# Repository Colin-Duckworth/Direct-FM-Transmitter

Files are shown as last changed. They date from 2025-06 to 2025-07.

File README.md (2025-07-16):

# Direct FM Transmitter (80-115 MHz)

A component-level FM transmitter designed from scratch to demonstrate RF system design and PCB layout skills for applications in low-power, narrowband wireless communication.

## Project Overview

As of revision MK4, the system has been fully re-engineered to prioritize **manufacturability, affordability, and modular signal control**. The transmitter features:

- A **free-running VCO** directly modulated with an analog signal to produce wideband FM
- A **TI LMK61E2 programmable oscillator** used in place of a PLL synthesizer, simplifying the frequency control architecture while maintaining tunability and spectral stability
- A **mixer stage** that upconverts the modulated VCO signal using the oscillator output, enabling frequency offset generation
- A flexible **filtering stage**, configurable between a custom-designed 3–5 pole Butterworth bandpass filter and a wideband SAW filter depending on use case
- A **transformer balun** to convert 200 Ω differential signals to 50 Ω single-ended, improving impedance matching for the final power amplifier
- A two-stage **low-power RF amplifier chain** redesigned for improved linearity and thermal stability under higher output drive
- A **programmable digital potentiometer** in the VCO modulation path to dynamically adjust FM deviation and bandwidth
- An **on-board microcontroller interface** with tuning knob for real-time center frequency control
- Full **impedance matching** between all major blocks using standard-value passives and Pi attenuators to ensure operation within amplifier P1dB
- A layout optimized for **low-cost 4-layer PCB fabrication**, using only **common, non-exotic components** to minimize BOM cost and unique part count for low-volume assembly services like JLCPCB
- RF test points and SMA-tapped outputs for validation and debugging

The complete signal chain was simulated, measured, and iteratively refined based on real VNA and spectrum analyzer results, making this project both a learning platform and a functional RF transmitter.

## 🔁 Revision History

| Version | Date | Summary of Changes |
|---|---|---|
| **MK4** | 2025-07-14 | - Fully redesigned PCB to prioritize affordable manufacturability, minimizing unique component count and relying solely on standard, non-exotic passive components available from major low-cost assembly houses<br>- Replaced PLL synthesizer with the TI LMK61E2 programmable oscillator, simplifying frequency generation and reducing BOM complexity |
| **MK3** | 2025-07-03 | - Replaced previous fixed-frequency SAW filter with a wideband SAW filter to support flexible carrier generation<br>- Inserted a transformer balun after the SAW filter to convert 200 Ω differential output to 50 Ω single-ended, improving impedance matching and integration with the final PA<br>- Added low-noise preamplifiers before the passive mixer stage to improve upconversion SNR and mixer drive levels<br>- Modified the power amplifier chain for improved linearity and thermal performance under increased output drive<br>- Introduced a programmable digital potentiometer in the VCO modulation path to dynamically control modulation bandwidth, allowing application-specific FM deviation tuning<br>- Narrowed and finalized the carrier frequency range to 80–115 MHz for better compatibility with existing commercial and amateur FM-band antennas<br>- Integrated a microcontroller-interfaced tuning knob (potentiometer) to set center frequency, allowing real-time adjustment of carrier offset without reprogramming<br>- Added a level shifter IC between microcontroller I/O and the PLL synthesizer’s SPI interface to ensure proper logic-level compatibility |
| **MK2** | 2025-06-13 | - Replaced 50 MHz SAW filter with custom 3rd-order Butterworth filter to reduce insertion loss (~11 dB → <1 dB)<br>- Added second-stage amplifier to boost output power into 10–20 dBm range<br>- Inserted impedance-matched Pi attenuator before PA stages to ensure operation within P1dB<br>- Removed redundant RF tap after final amplifier (will probe SMA output directly if needed)<br>- Moved PLL Synth power supply from external microcontroller to on board power plane |
| **MK1** | 2025-05-02 | - Initial layout fabricated but not assembled<br>- SAW filter chain insertion loss (~15 dB) resulted in poor power budget<br>- No sufficient gain staging; final output estimated <1 mW<br>- Identified layout and topology flaws upon physical inspection<br>- Informed redesign of gain chain, filtering, and impedance matching in MK2 |

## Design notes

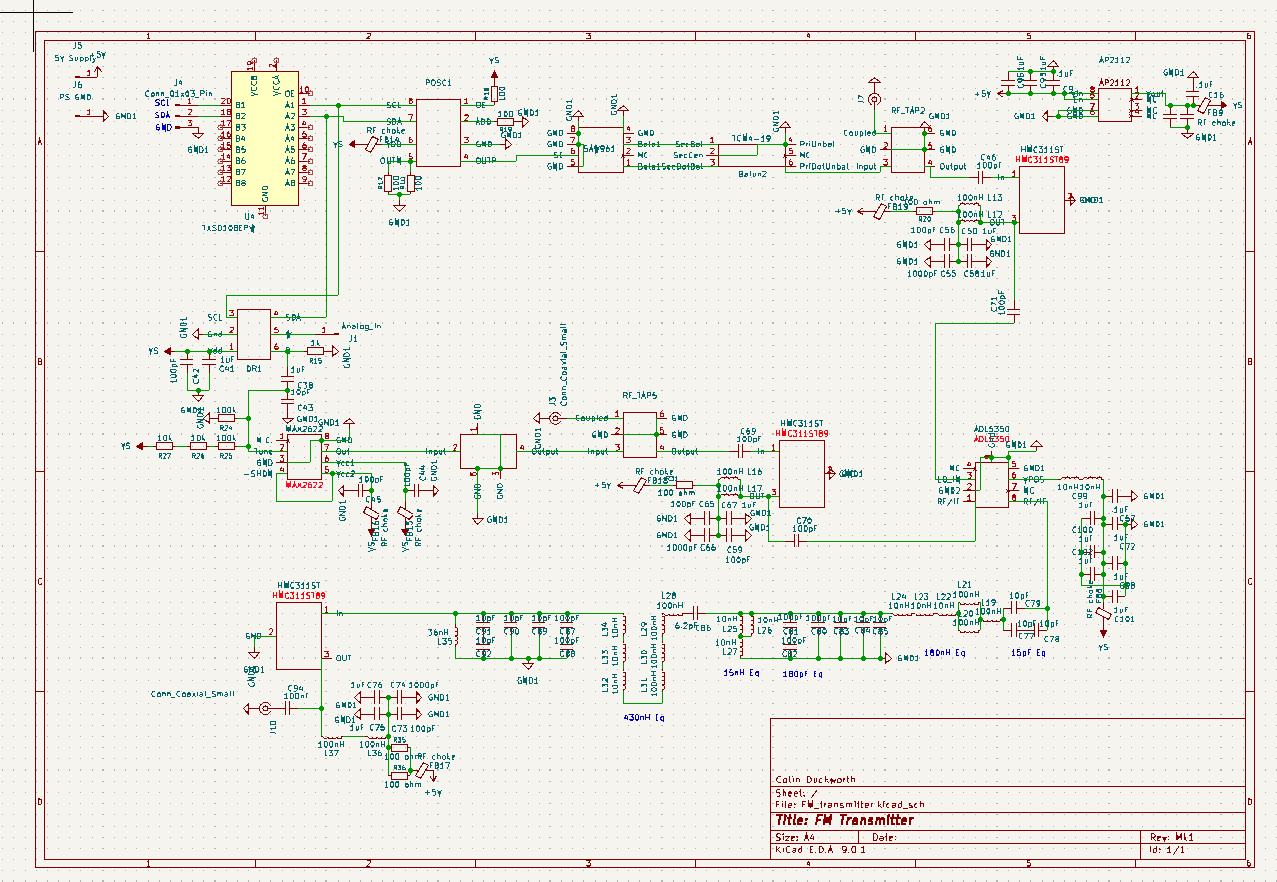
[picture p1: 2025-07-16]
Schematics/Mk4/Mk4 Schematic.png

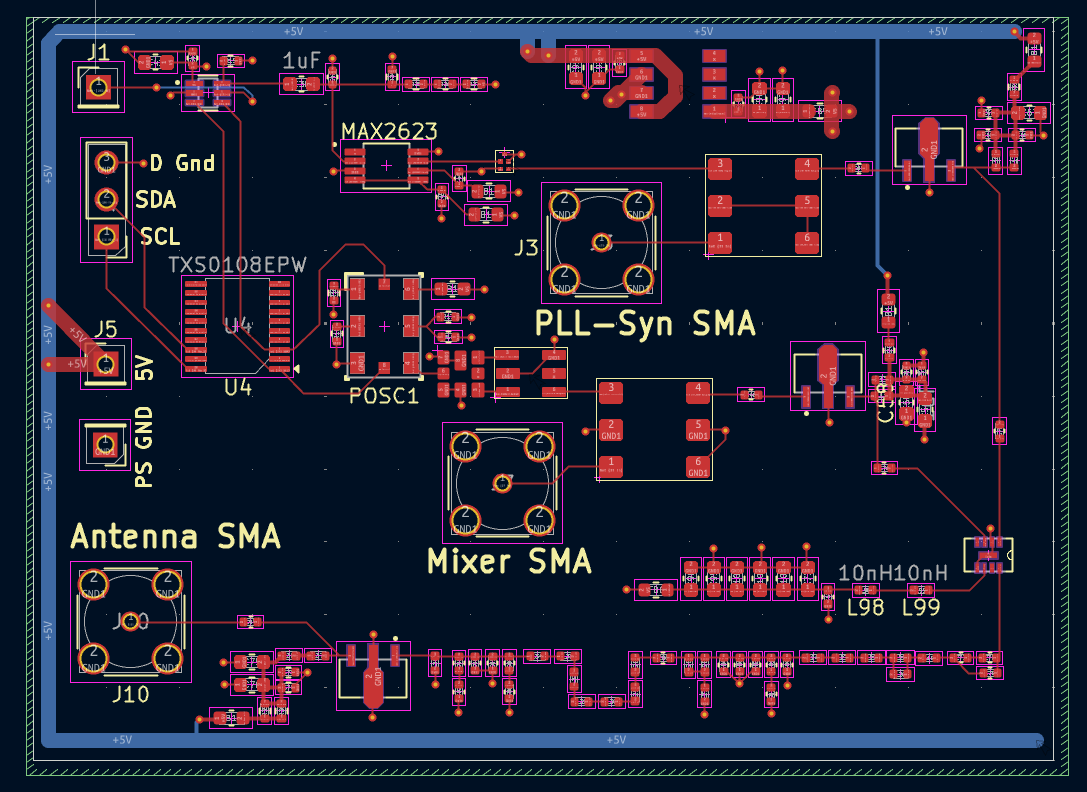
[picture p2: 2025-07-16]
PCB/Mk4/Mk4 PCB Png.png

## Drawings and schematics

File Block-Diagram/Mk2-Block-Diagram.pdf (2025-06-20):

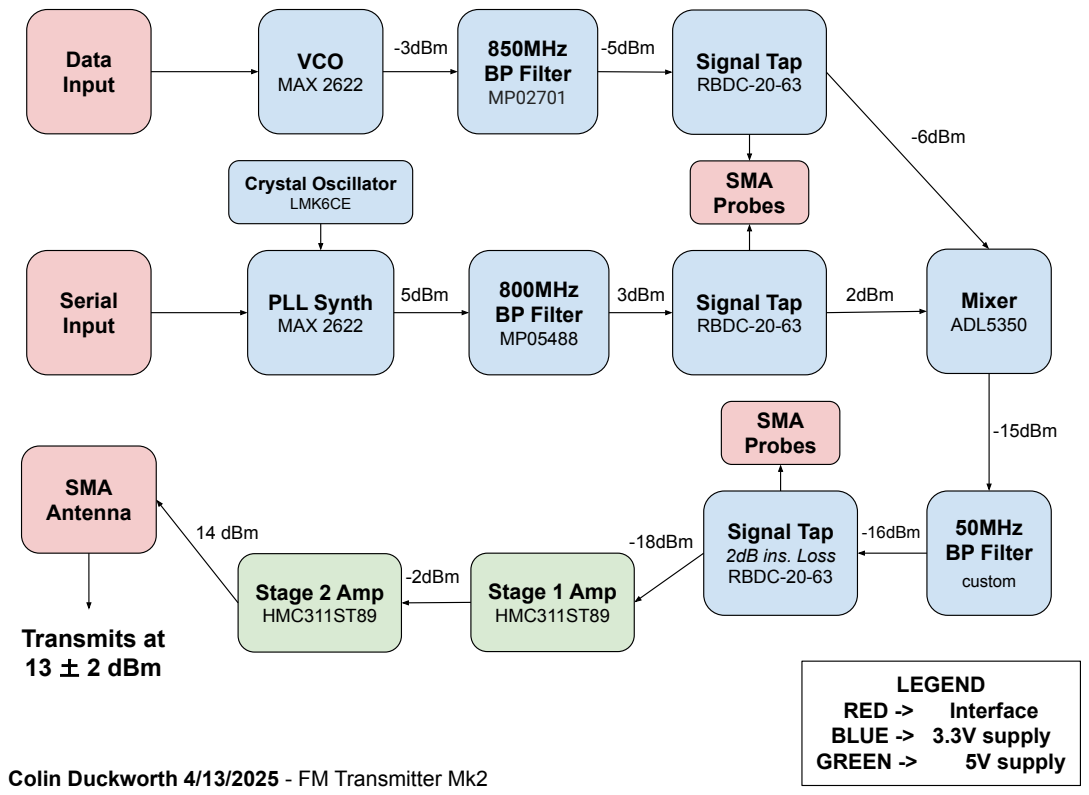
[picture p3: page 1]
VCO MAX 2622; PLL Synth MAX 2622; Mixer ADL5350; 850MHz BP Filter MP02701; 800MHz BP Filter MP05488; 50MHz BP Filter; HMC311ST89; Data Input; Signal Tap RBDC-20-63; Serial Input; SMA Probes; Signal Tap 2dB ins. Loss RBDC-20-63; SMA Antenna; LEGEND; RED ->; Interface; BLUE -> 3.3V supply; GREEN ->; 5V supply; Crystal Oscillator LMK6CE; Stage 2 Amp HMC311ST89; 5dBm; 3dBm; 2dBm; -3dBm; -5dBm; -6dBm; -2dBm; -16dBm -18dBm 14 dBm; Transmits at 13 土 2 dBm; -15dBm

custom Stage 1 Amp

Colin Duckworth 4/13/2025 - FM Transmitter Mk2

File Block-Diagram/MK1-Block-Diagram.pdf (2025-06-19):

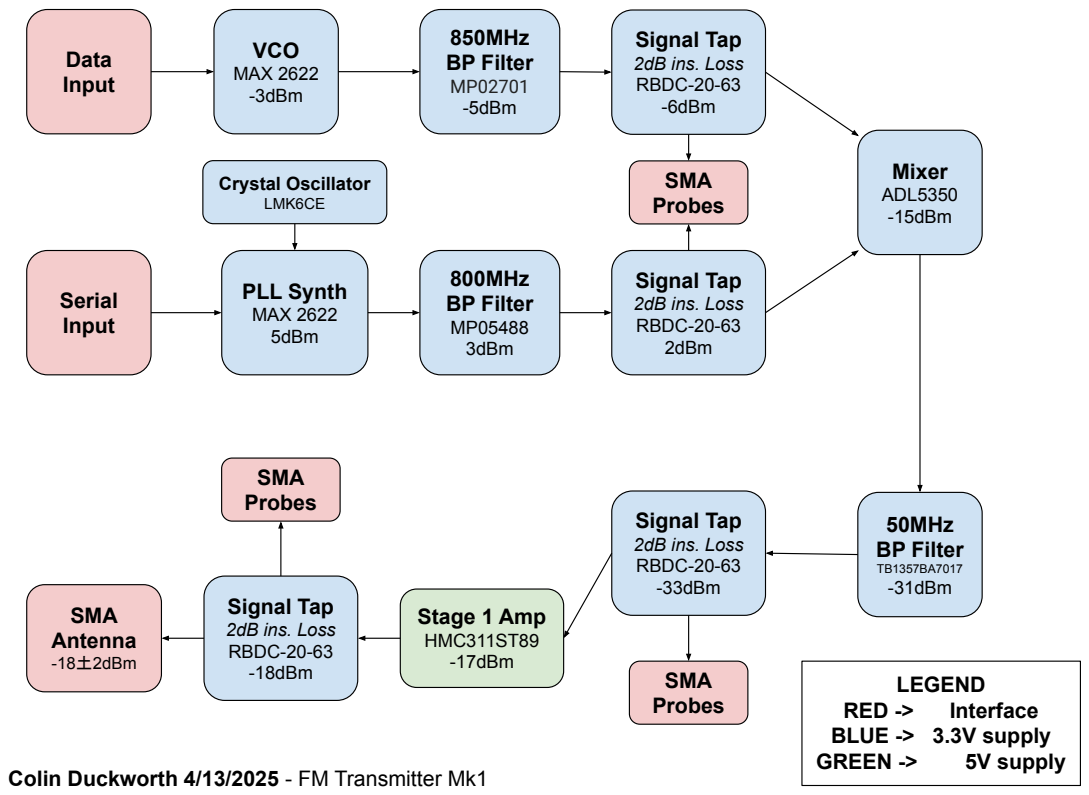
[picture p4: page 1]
VCO MAX 2622 -3dBm; PLL Synth MAX 2622 5dBm; Mixer ADL5350 -15dBm; 850MHz BP Filter MP02701 -5dBm; 800MHz BP Filter MP05488 3dBm; 50MHz BP Filter; TB1357BA7017 -31dBm; Stage 1 Amp HMC311ST89 -17dBm; Data Input; Signal Tap 2dB ins. Loss RBDC-20-63 2dBm; Serial Input; SMA Probes; Signal Tap 2dB ins. Loss RBDC-20-63 -6dBm; Signal Tap 2dB ins. Loss RBDC-20-63 -33dBm; SMA Antenna -18土2dBm; LEGEND; RED ->; Interface; BLUE -> 3.3V supply; GREEN ->; 5V supply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

Colin Duckworth 4/13/2025 - FM Transmitter Mk1

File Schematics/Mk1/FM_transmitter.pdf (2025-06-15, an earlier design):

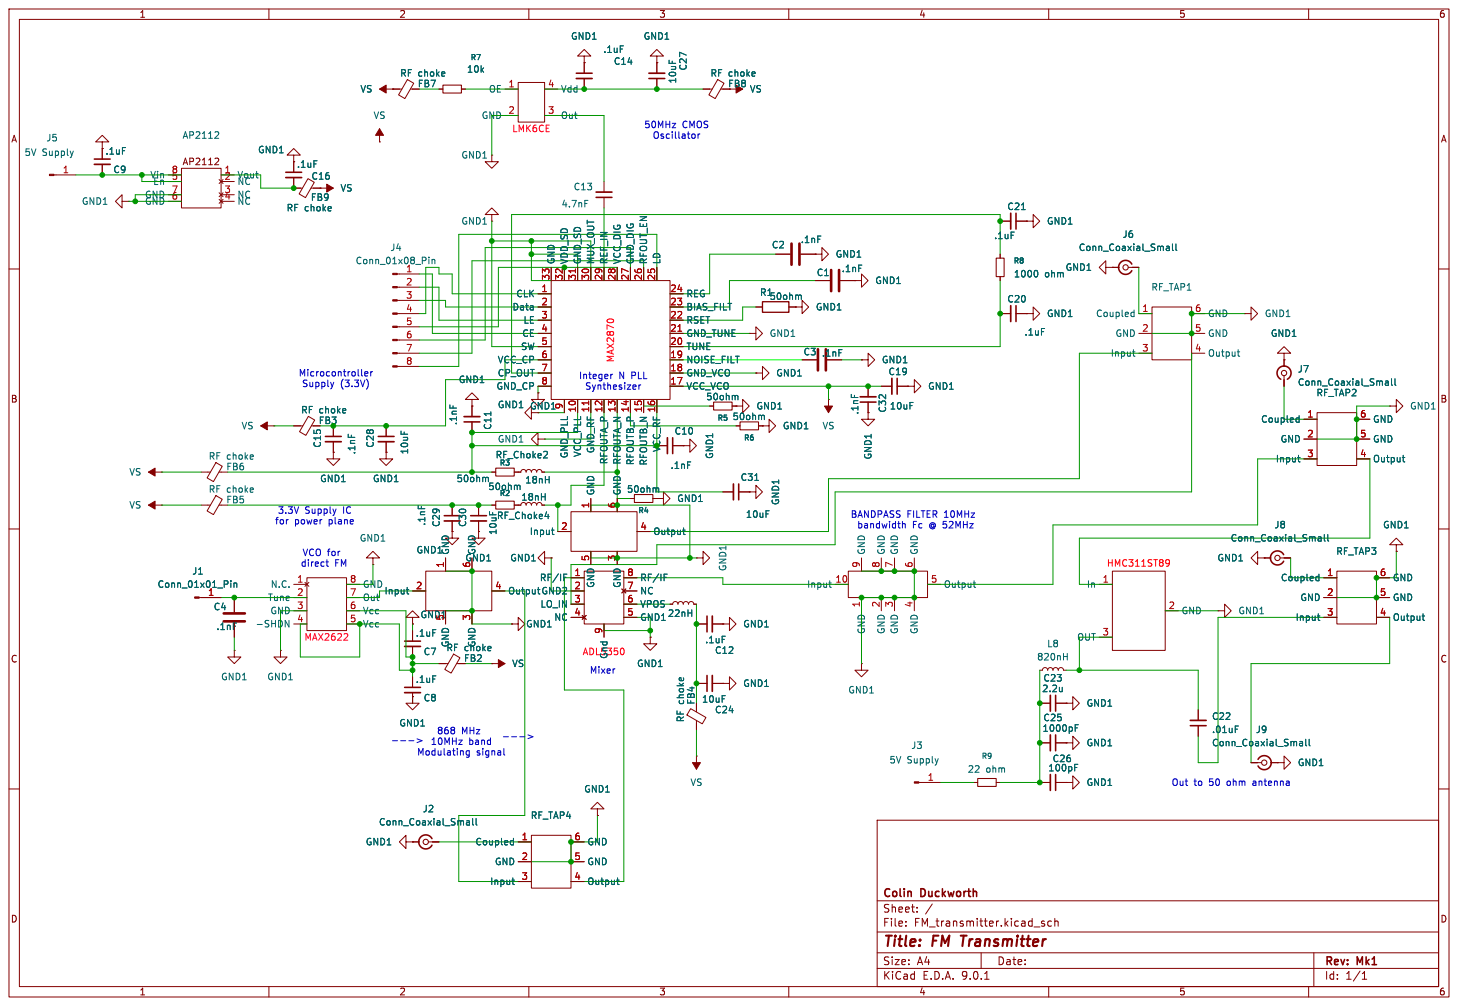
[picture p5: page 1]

9 RF/IF 8 NC 7 VPOS 6 GND1 5 GND1 R4 50ohm

9 RF/IF 8 NC 7 VPOS 6 GND1 5 GND1

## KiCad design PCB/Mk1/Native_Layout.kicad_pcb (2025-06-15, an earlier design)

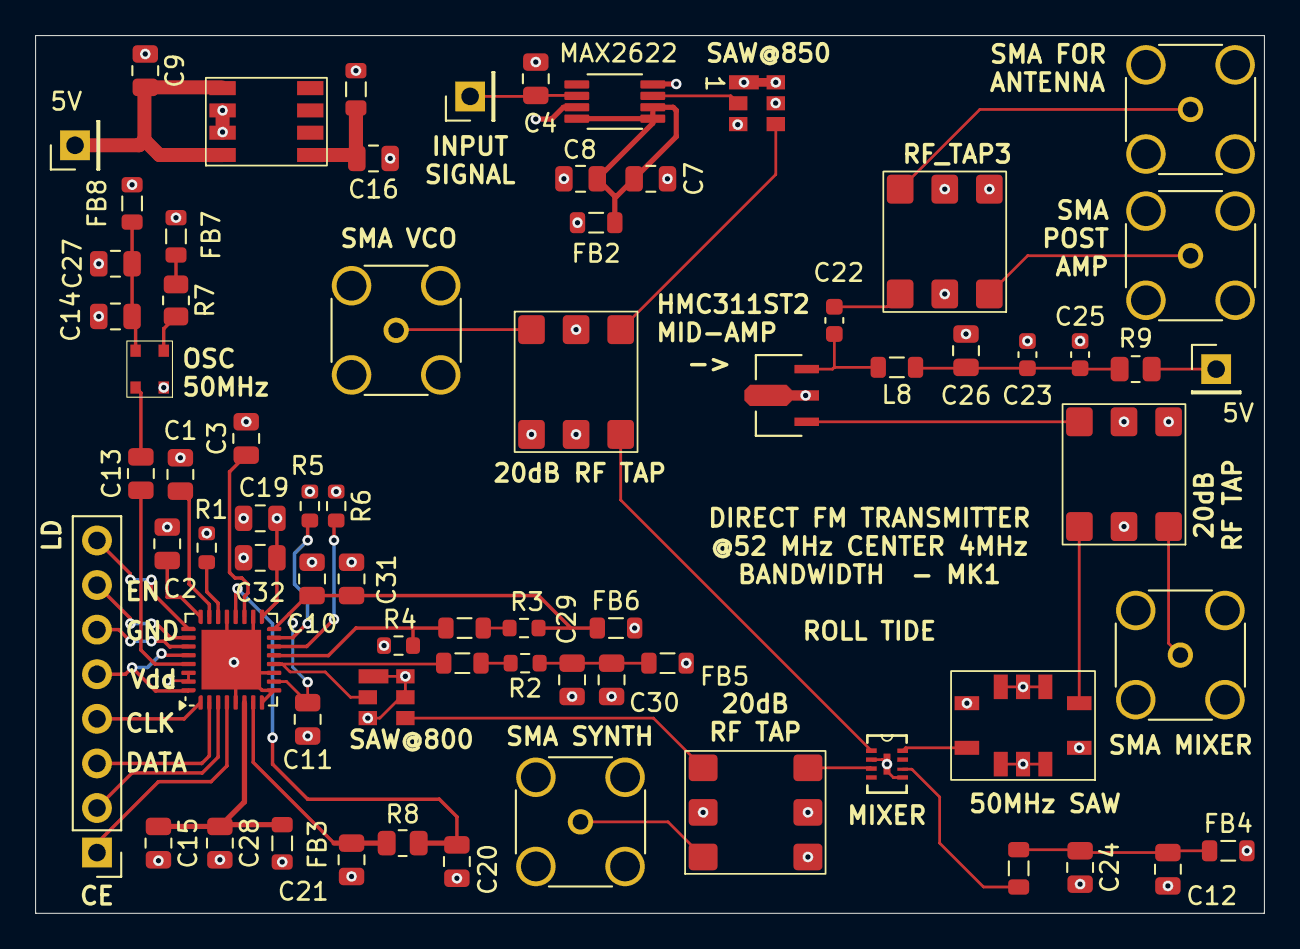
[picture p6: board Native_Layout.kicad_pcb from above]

Board: 4 copper layers, 70.0 x 50.0 mm, 71 parts (0 on the bottom side), 53 nets.

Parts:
5V, 5V#2: 5V Supply; PinHeader_1x01_P2.54mm_Vertical
ADL1: CP-8-1
AP2112: SO-8 (AP2112)
C1, C2, C3, C4, C15, C29, C32: .1nF; C_0805_2012Metric
C7, C8, C9, C12, C14, C16, C20, C21: .1uF; C_0805_2012Metric
C10, C11: Decoup Cap; C_0805_2012Metric
C13: 4.7nF; C_0805_2012Metric
C19, C24, C27, C28, C30: 10uF; C_0805_2012Metric
C22: .01uF; C_0603_1608Metric
C23: 2.2u; C_0603_1608Metric
C25: 1000pF; C_0603_1608Metric
C26: 100pF; C_0805_2012Metric
C31: Bank Cap; C_0805_2012Metric
CE: Conn_01x08_Pin; PinHeader_1x08_P2.54mm_Vertical
FB2, FB3, FB4, FB5, FB6, FB7, FB8, FB9: RF choke; L_0805_2012Metric
HMC311ST2: SOT-89
J1: Conn_01x01_Pin; PinHeader_1x01_P2.54mm_Vertical
J2, J6, J7, J8, J9: Conn_Coaxial_Small; SMA_Amphenol_132134-14_Vertical
L8: 820nH; L_0805_2012Metric
MAX1: TQFN-32-1EP_5x5mm_P0.5mm_EP3.4x3.4mm
MAX2622: 8uMAX
R1, R2, R3, R4, R5, R6: 50ohm; R_0603_1608Metric
R7: 10k; R_0805_2012Metric
R8: 1000 ohm; R_0805_2012Metric
R9: 22 ohm; R_0805_2012Metric
RF_Choke2, RF_Choke4: 18nH; L_0805_2012Metric
RF_Choke3: 22nH; L_0805_2012Metric
RF_TAP1, RF_TAP2, RF_TAP3, RF_TAP4: RBDC-20
SAW@50: TAI-SAW Filter
SAW@800, SAW@850: Golledge SAW Footprint
U2: 4-Pin VSON (LMK6CE)

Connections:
GND1: ADL1.2 (GND2), ADL1.5 (GND1), ADL1.9 (Gnd), AP2112.6 (GND), AP2112.7 (GND), C1.2, C2.2, C3.2, C4.2, C7.1, C8.2, C9.1, C10.1, C11.2, C12.2, C14.1, C15.2, C16.1, C19.1, C20.1, C21.1, C23.1, C24.2, C25.1, C26.1, C27.2, C28.2, C29.2, C30.2, C31.1, C32.1, HMC311ST2.2 (GND), J2.2 (Ext), J6.2 (Ext), J7.2 (Ext), J8.2 (Ext), J9.2 (Ext), MAX1.5 (SW), MAX1.8 (GND_CP), MAX1.9 (GND_PLL), MAX1.11 (GND_RF), MAX1.18 (GND_VCO), MAX1.21 (GND_TUNE), MAX1.30 (MUX_OUT), MAX1.31 (GND_SD), MAX1.33 (GND), MAX2622.3 (GND), MAX2622.8 (GND), R1.2, R4.1, R5.1, R6.1, RF_TAP1.2 (GND), RF_TAP1.5 (GND), RF_TAP1.6 (GND), RF_TAP2.2 (GND), RF_TAP2.5 (GND), RF_TAP2.6 (GND), RF_TAP3.2 (GND), RF_TAP3.5 (GND), RF_TAP3.6 (GND), RF_TAP4.2 (GND), RF_TAP4.5 (GND), RF_TAP4.6 (GND), SAW@50.1 (GND), SAW@50.2 (GND), SAW@50.3 (GND), SAW@50.4 (GND), SAW@50.6 (GND), SAW@50.7 (GND), SAW@50.8 (GND), SAW@50.9 (GND), SAW@800.1 (GND), SAW@800.3 (GND), SAW@800.5 (GND), SAW@800.6 (GND), SAW@850.1 (GND), SAW@850.3 (GND), SAW@850.5 (GND), SAW@850.6 (GND), U2.2 (GND)
unnamed: ADL1.3 (LO_IN), RF_TAP1.4 (Output)
unnamed: ADL1.6 (VPOS), RF_Choke3.1
unnamed: 5V.1, AP2112.5 (En), AP2112.8 (Vin), C9.2
unnamed: AP2112.1 (Vout), C16.2, FB9.1
unnamed: C12.1, C24.1, FB4.1, RF_Choke3.2
unnamed: C23.2, C25.2, C26.2, L8.1, R9.2
unnamed: C29.1, C30.1, FB5.1, R2.1
unnamed: FB7.1, R7.1
unnamed: HMC311ST2.1 (In), RF_TAP2.4 (Output)
unnamed: C22.2, HMC311ST2.3 (OUT), L8.2
unnamed: C4.1, J1.1, MAX2622.2 (Tune)
unnamed: J2.1 (In), RF_TAP4.1 (Coupled)
unnamed: 5V#2.1, R9.1
unnamed: CE.1, MAX1.4 (CE)
unnamed: CE.2, MAX1.3 (LE)
unnamed: CE.3, MAX1.2 (Data)
unnamed: CE.4, MAX1.1 (CLK)
unnamed: CE.5, MAX1.28 (VCC_DIG), MAX1.32 (VDD_SD)
unnamed: CE.6, MAX1.27 (GND_DIG)
unnamed: CE.7, MAX1.26 (RFOUT_EN)
unnamed: CE.8, MAX1.25 (LD)
unnamed: J6.1 (In), RF_TAP1.1 (Coupled)
unnamed: J7.1 (In), RF_TAP2.1 (Coupled)
unnamed: J8.1 (In), RF_TAP3.1 (Coupled)
unnamed: J9.1 (In), RF_TAP3.4 (Output)
unnamed: C1.1, MAX1.23 (BIAS_FILT)
unnamed: C21.2, MAX1.7 (CP_OUT), R8.1
unnamed: C3.1, MAX1.19 (NOISE_FILT)
unnamed: C13.1, MAX1.29 (REF_IN)
unnamed: C2.1, MAX1.24 (REG)
unnamed: MAX1.13 (RFOUTA_N), R4.2, RF_Choke2.2
unnamed: MAX1.12 (RFOUTA_P), RF_Choke4.2, SAW@800.2 (Input)
unnamed: MAX1.15 (RFOUTB_N), R5.2
unnamed: MAX1.14 (RFOUTB_P), R6.2
unnamed: MAX1.22 (RSET), R1.1
unnamed: C20.2, MAX1.20 (TUNE), R8.2
unnamed: C15.1, C28.1, FB3.1, MAX1.6 (VCC_CP)
unnamed: C10.2, C11.1, C31.2, FB6.1, MAX1.10 (VCC_PLL), MAX1.16 (VCC_RF), R3.1
unnamed: C7.2, C8.1, FB2.2, MAX2622.4 (-SHDN), MAX2622.5 (Vcc), MAX2622.6 (Vcc)
unnamed: MAX2622.7 (Out), SAW@850.2 (Input)
unnamed: R2.2, RF_Choke4.1
unnamed: R3.2, RF_Choke2.1
unnamed: RF_TAP1.3 (Input), SAW@800.4 (Output)
unnamed: RF_TAP2.3 (Input), SAW@50.5 (Output)
unnamed: C22.1, RF_TAP3.3 (Input)
unnamed: RF_TAP4.3 (Input), SAW@850.4 (Output)
unnamed: ADL1.1 (RF/IF), RF_TAP4.4 (Output)
unnamed: ADL1.8 (RF/IF), SAW@50.10 (Input)
unnamed: R7.2, U2.1 (OE)
unnamed: C13.2, U2.3 (Out)
unnamed: C14.2, C27.1, FB8.2, U2.4 (Vdd)
VS: C19.2, C32.2, FB2.1, FB3.2, FB4.2, FB5.2, FB6.2, FB7.2, FB8.1, FB9.2, MAX1.17 (VCC_VCO)

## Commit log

2025-06-15 Rename Screenshot 2025-06-15 162407.png to PCB.png
2025-06-15 Update and rename FM_transmitter.kicad_pcb to Native_Layout.kicad_pcb
    [Native_Layout.kicad_pcb]
2025-07-16 Rename Screenshot 2025-07-15 203506.png to Mk4 PCB Png
2025-07-16 Rename Schematics/Screenshot 2025-07-15 203802.png to Schematics/Mk4/Screenshot 2025-07-15 203802.png
2025-07-16 Rename Screenshot 2025-07-15 203802.png to Mk4 Schematic.png
2025-07-16 Rename Mk4 PCB Png to Mk4 PCB Png.png
2025-07-16 Rename PCB/GERBER-FM_transmitter.zip to PCB/Mk3/PCB Mk3.zip
